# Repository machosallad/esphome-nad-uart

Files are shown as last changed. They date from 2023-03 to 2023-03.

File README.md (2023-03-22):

# ESPHome controller for NAD C356BEE

Control NAD C356BEE through RS232 from Home Assistant (HA) using ESPHome and a Wemos D1. The ESPhome configuration exposes the following entities to HA:

- Power
- Sources
- Mute
- Speaker A/B
- Volume increment and decrement

The entities are queried during startup and will automatically be updated based on the information received from the amplifier.
Volume entities are state-less and therefore configured as buttons compared to the other entities which are configured as switches.

D1|300

## Resources

The UART text sensor used for ESPHome is based on the description at [Custom UART Text Sensor](https://esphome.io/cookbook/uart_text_sensor.html).

## Hardware

- MAX3232 RS232 Serial Port to TTL Conversion Module
- Wemos D1
- Null modem cable

### Wiring

| Wemos D1 | MAX3232 |
| --- | --- |
| D4 | TX |
| D3 | RX |
| GND | GND |
| 3.3 | VCC |

## C356BEE RS232 command list

Set the baud rate to `115200` to properly send and receive serial data from C356BEE. A reference for these commands can be
found on this [webpage](https://www.yumpu.com/en/document/read/35405103/c356-rs232-command-list-nad-electronics-main-lektropacks).

| Command | Operators | Possible values | Description | Example |
| --- | --- | --- | --- | --- |
| `Main.Model` | ? | N/A | Query model | `Main.Model?` |
| `Main.Mute` | =/+/-/? | On, Off | Set mute | `Main.Mute=On` |
| `Main.Power` | =/+/-/? | On, Off | Set power on/off | `Main.Power=On` |
| `Main.Source` | =/+/-/? | TAPE2, DISC/MDC, MP, TUNER, AUX, CD | Set source | `Main.Source=CD` |
| `Main.SpeakerA` | =/+/-/? | On, Off | Set speaker A on/off | `Main.SpeakerA=On`  |
| `Main.SpeakerB` | =/+/-/? | On, Off | Set speaker B on/off | `Main.SpeakerB=Off` |
| `Main.Tape1` | =/+/-/? | On, Off | Set tape 1 on/off | `Main.Tape1=On` |
| `Main.Volume` | +/- | N/A | Increment or decrement volume | `Main.Volume+` |

## 3D printed case

The case and cover can be printed using a filament printer in order to store the electronics neatly.

## Useful insights

Make sure to connect the Rx and Tx pins properly between the nodes that need to communicate. I had a problem with my amplifier and
MAX3232 where I used a straight cable instead of a twisted/null cable, which caused the devices to not communicate with each other.
It took me a long time to realize this mistake.

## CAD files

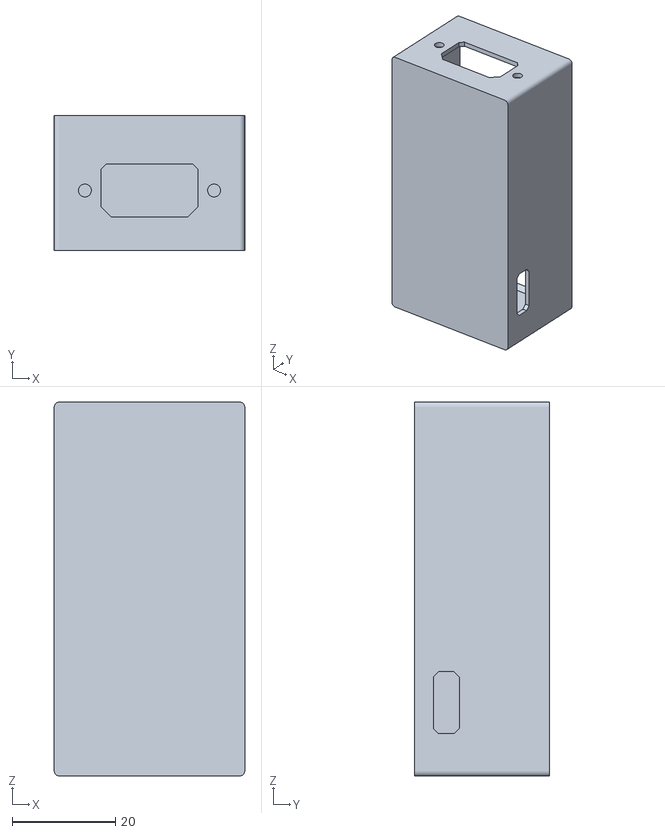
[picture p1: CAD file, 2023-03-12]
STL/D1_Case.stl
36.9 x 26.2 x 72.4

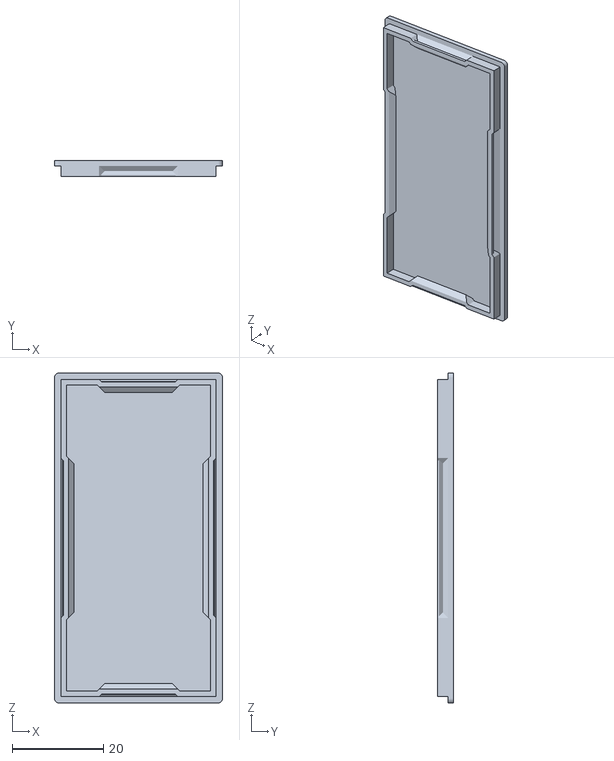
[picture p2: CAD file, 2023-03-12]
STL/D1_Cover.stl
36.9 x 3.60 x 72.4

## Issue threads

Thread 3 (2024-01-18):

Any idea to set volume to wanted dB?

Trilis29, 2024-01-18:

machosallad, 2024-01-18:
I guess it would be fully dependent on the amplifier/equipment in question you attempt to control. Have you got hold of the list of available commands in your case, or are you also attempting to control a NAD C356?

Trilis29, 2024-01-18:
I have C388, I suppose should be the same as 356

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

machosallad, 2024-01-19:
You need to verify the available commands for your model, if it has additional capabilites related to volume or not. Possible options are dependent on this.

Trilis29, 2024-02-09:
volume should be possible with simple "=" operator.  Just need to implement in esphome that it reads on boot volume aswell and need maybe number entity for setting volume. through  - uart.write: "\rMain.Volume=\r"

machosallad, 2024-02-09:
That is how ever not the case. The reference manual I have linked in README.md clearly states that the "=" operator is not supported [reference](https://www.yumpu.com/en/document/read/35405103/c356-rs232-command-list-nad-electronics-main-lektropacks).

As it mentions, discrete values for the volume is not possible due to the motorised volume control. If you wish to set the volume to a predefined volume, you cannot rely on the amplifier for this handling. It has do be done in some other matter with custom code.
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

Trilis29, 2024-02-09:
This is from C368/388 manual, seems it is possible. Would you consider to write aditional configuration for this? :)

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

machosallad, 2024-02-09:
Then you're in luck! I have no intention to expand my configuration with unsupported commands for my model. I would advise you to create a fork of my repository and perform the required additions to the configuration file to get/set volume and create new lambdas & actions to control it.

Trilis29, 2024-02-10:
setting volume is possible, but maybe you know how I can convert string to float of Main.Volume=-24.5 for example? I need lambda to update volume number component so I could control volume from HA

machosallad, 2024-02-10:
Assume you should be using atoi/atof or similar methods: https://cplusplus.com/reference/cstdlib/atof/

Trilis29, 2024-02-12:
So I got volume working, also made a number slider which can be used with universal media player enitty to create media player in home assistant. But in home assistant need 2 helper entities:
1. Convert dB to 0..1 scale for media_player volume_level
2. Convert 0..1 scale from volume_level slider in media_player again to -70dB and send to service number set to uppdate value.

Number component should have uart.write action aswell:
`number:
  - platform: template
    name: "Current Volume"
    id: current_volume
    min_value: -70
    max_value: 0
    step: 0.5
    icon: "mdi:volume-high"
    set_action:
      then:
      - uart.write:
          id: uart_bus
          data: !lambda |-
              std::size_t pos;
              std::string str = "\rMain.Volume=" + std::to_string(x) + "\r";
              while ((pos = str.find("\\r")) != std::string::npos)
                str.replace(pos, 2, "\r");
              std::vector<uint8_t> vec(str.begin(), str.end());
              return vec; `

Also updated text_sensor so on_value lambda should update number component:
`text_sensor:
- platform: custom
  lambda: |-
    auto my_custom_sensor = new UartReadLineSensor(id(uart_bus));
    App.register_component(my_custom_sensor);
    return {my_custom_sensor};
  text_sensors:
    id: "uart_readline"
    on_value:
      then:
      - lambda: |-
              std::string sensorState = id(uart_readline).state;
              if (sensorState.length() > 0) {
                size_t index = sensorState.find("Main.Volume=");
                if (index != std::string::npos) {
                  std::string floatValueStr = sensorState.substr(index + 12);
                  float floatValue = atof(floatValueStr.c_str());
                  id(current_volume).publish_state(floatValue);
                }
              }`

Maybe everything could be done better way, still looking into. When will be finished I will make fork with full configuration for esphome and homeassistant to integrate with media_player, then would be possible to use fully with homekit, google home or assist to control anything :)

Closed 2024-03-09.

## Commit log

2023-03-12 Update README
    Include information about commands, wiring, hardware etc.
2023-03-12 Add configuration and header files
    Inclunde configuration for ESPHome and header file for the UART.
2023-03-12 Add STL files for the project
    Case and cover used to contain the electronics.
    [D1_Case.stl, D1_Cover.stl]
2023-03-22 Update the README
    - Listed of entities updated.
    - Missing word "cable" added for the HW.
    - Reference to commands added.
    - Section for the case changed.
    - Added insights of the build.
